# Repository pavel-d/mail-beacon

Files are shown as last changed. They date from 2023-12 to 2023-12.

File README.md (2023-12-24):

# Mail Beacon

The Mailbox Beacon is a device that detects when a new letter or package has been delivered to your mailbox using a reed switch. It sends a signal to your LoRa gateway, then the gateway sends a message via WiFi to MQTT server. It's designed to integrate with HomeAssistant, but can theoretically work with anything that supports MQTT based sensors.

Specification
--
- Microcontroller: Attiny1616
- Radio module: SX1278 LoRa 433 Mhz (Ai-Thinker-Ra-01)
- Sensor: Reed switch
- Voltage regulator: SPX3819M5-L-3-3
- Programming Protocol: UPDI
- Power consumption: in microamps range when asleep
- Gateway: LILYGO TTGO LoRa32 V2.1
- Status LED

Wiring
--
Reed switch (or any other kind of contact switch) must be connected either to PA4 or PA7 pins and to the GND. Pins have internal pull-ups enabled and are "active low", so the switch must pull the pin to the ground when circuit is closed. Both pins have interrupts attached, microcontroller will send a message to the gateway when the logic level changes.

TEST button also has an interrupt attached and can be used to test the setup.

Power LED has a jumper that can be cut to reduce the power consumption.

Battery monitoring
--
The beacon sends the battery voltage (in milivolts) in every LoRa packet, so that you know when you need to re-charge the battery.

Schematic
--
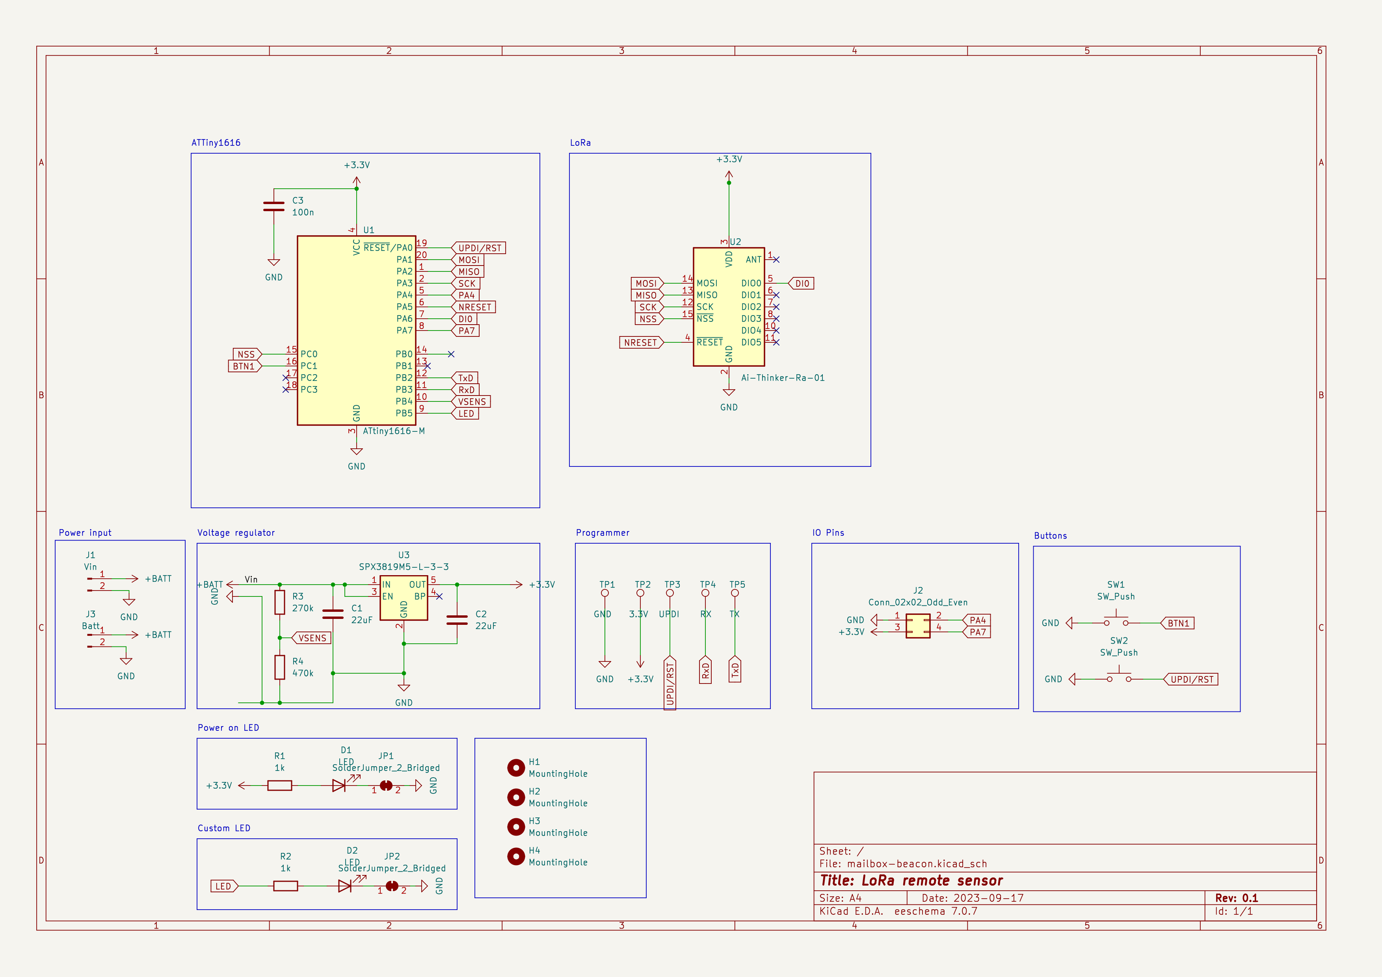
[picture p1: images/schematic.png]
schematic


Board
--
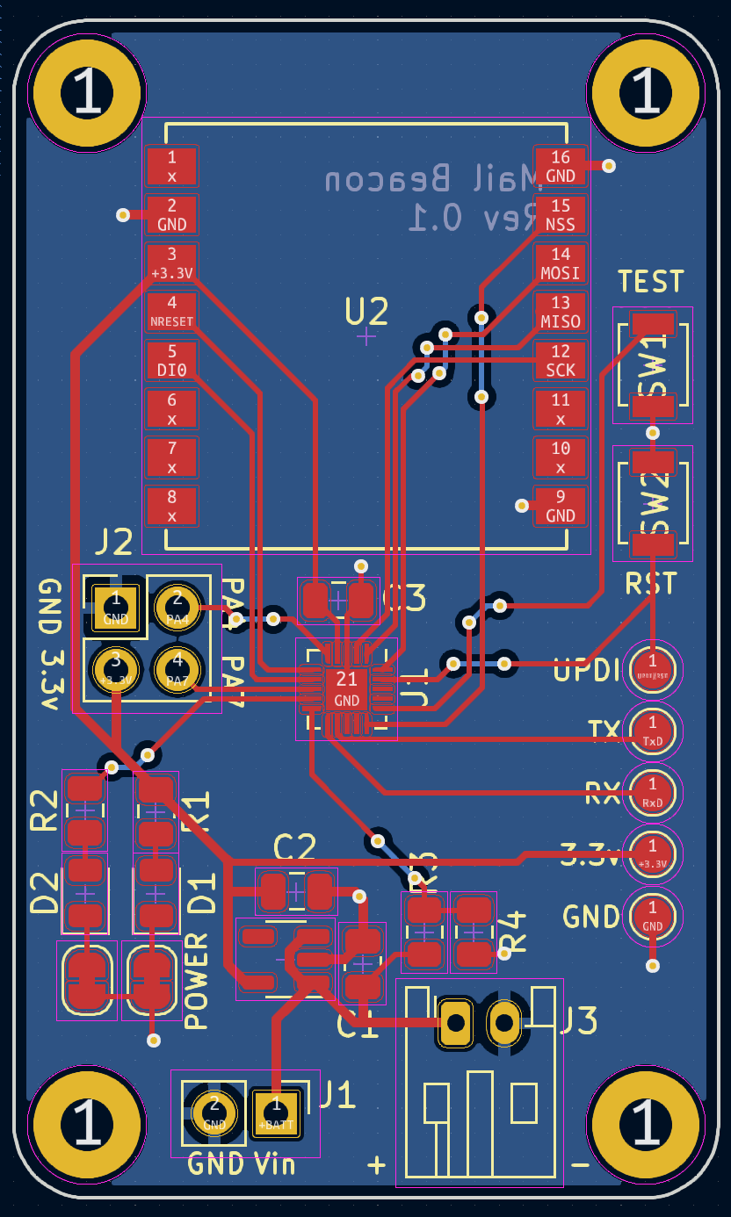
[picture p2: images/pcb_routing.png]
pcb


Images
--
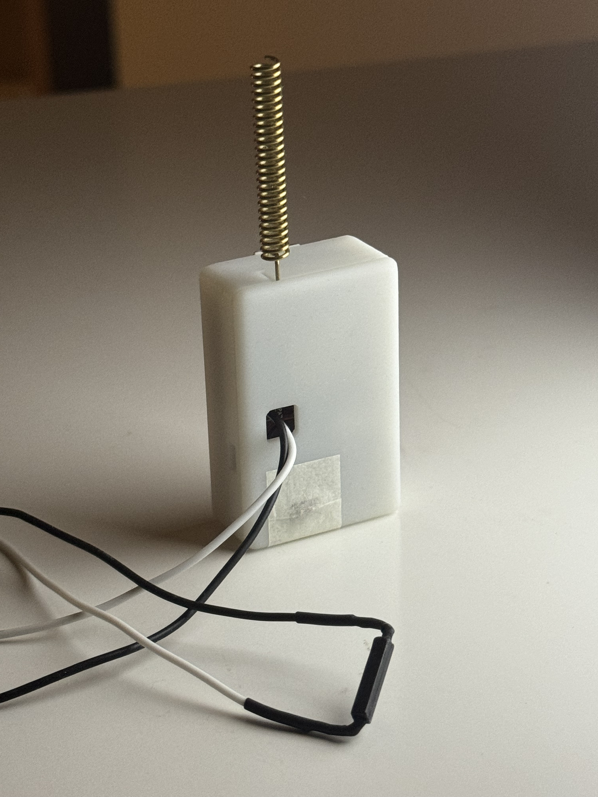
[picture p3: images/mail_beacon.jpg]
manufactured


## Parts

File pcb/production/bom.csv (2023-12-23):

Designator | Footprint | Quantity | Value | LCSC Part #
C1, C2 | 0805 | 2 | 22uF
C3 | 0805 | 1 | 100n
D1, D2 | 0805 | 2 | LED
H1, H2, H3, H4 | MountingHole_2.2mm_M2_Pad | 4 | MountingHole
J1 | PinHeader_1x02_P2.54mm_Vertical | 1 | Vin
J2 | PinHeader_2x02_P2.54mm_Vertical | 1 | Conn_02x02_Odd_Even
J3 | JST_PH_S2B-PH-K_1x02_P2.00mm_Horizontal | 1 | Batt
JP1, JP2 | SolderJumper-2_P1.3mm_Bridged_RoundedPad1.0x1.5mm | 2 | SolderJumper_2_Bridged
R1, R2 | 0805 | 2 | 1k
R3 | 0805 | 1 | 10k
R4 | 0805 | 1 | 20k
SW1, SW2 | SW_SPST_B3U-1000P | 2 | SW_Push
TP1 | TestPoint_Pad_D1.5mm | 1 | GND
TP2 | TestPoint_Pad_D1.5mm | 1 | 3.3V
TP3 | TestPoint_Pad_D1.5mm | 1 | UPDI
TP4 | TestPoint_Pad_D1.5mm | 1 | RX
TP5 | TestPoint_Pad_D1.5mm | 1 | TX
U1 | VQFN-20-1EP_3x3mm_P0.4mm_EP1.7x1.7mm | 1 | ATtiny1616-M
U2 | Ai-Thinker-Ra-01-LoRa | 1 | Ai-Thinker-Ra-01
U3 | SOT-23-5 | 1 | SPX3819M5-L-3-3

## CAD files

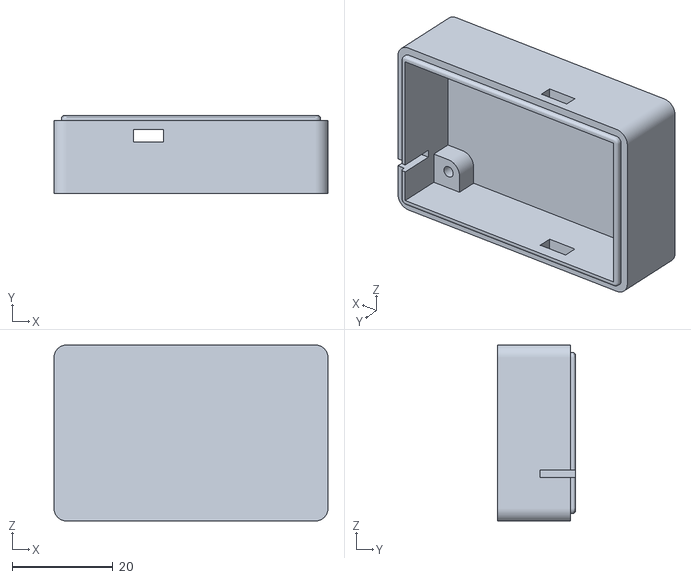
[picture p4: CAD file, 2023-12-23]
pcb/3dmodels/Case Bottom.stl
54.5 x 15.5 x 35.0

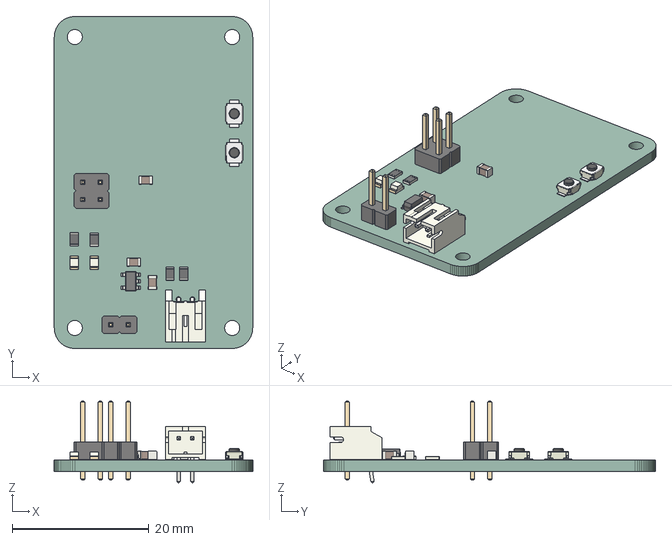
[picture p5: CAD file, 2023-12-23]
pcb/lora trigger attiny1616.step
29.0 x 48.5 x 11.9 mm
_autosave-lora trigger attiny1616 PCB

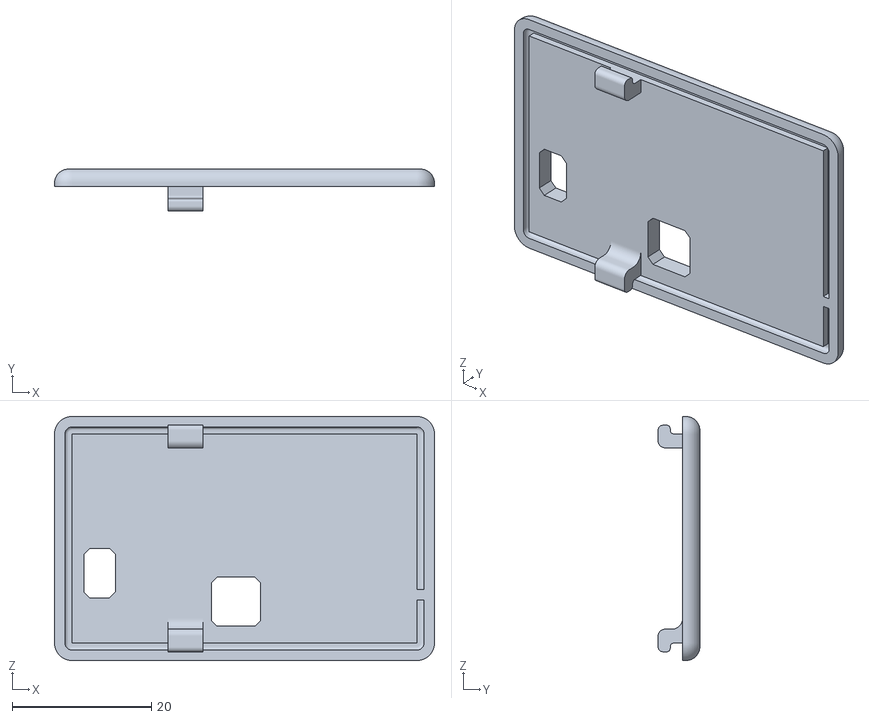
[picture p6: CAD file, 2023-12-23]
pcb/3dmodels/Case Top.stl
54.5 x 6.00 x 35.0

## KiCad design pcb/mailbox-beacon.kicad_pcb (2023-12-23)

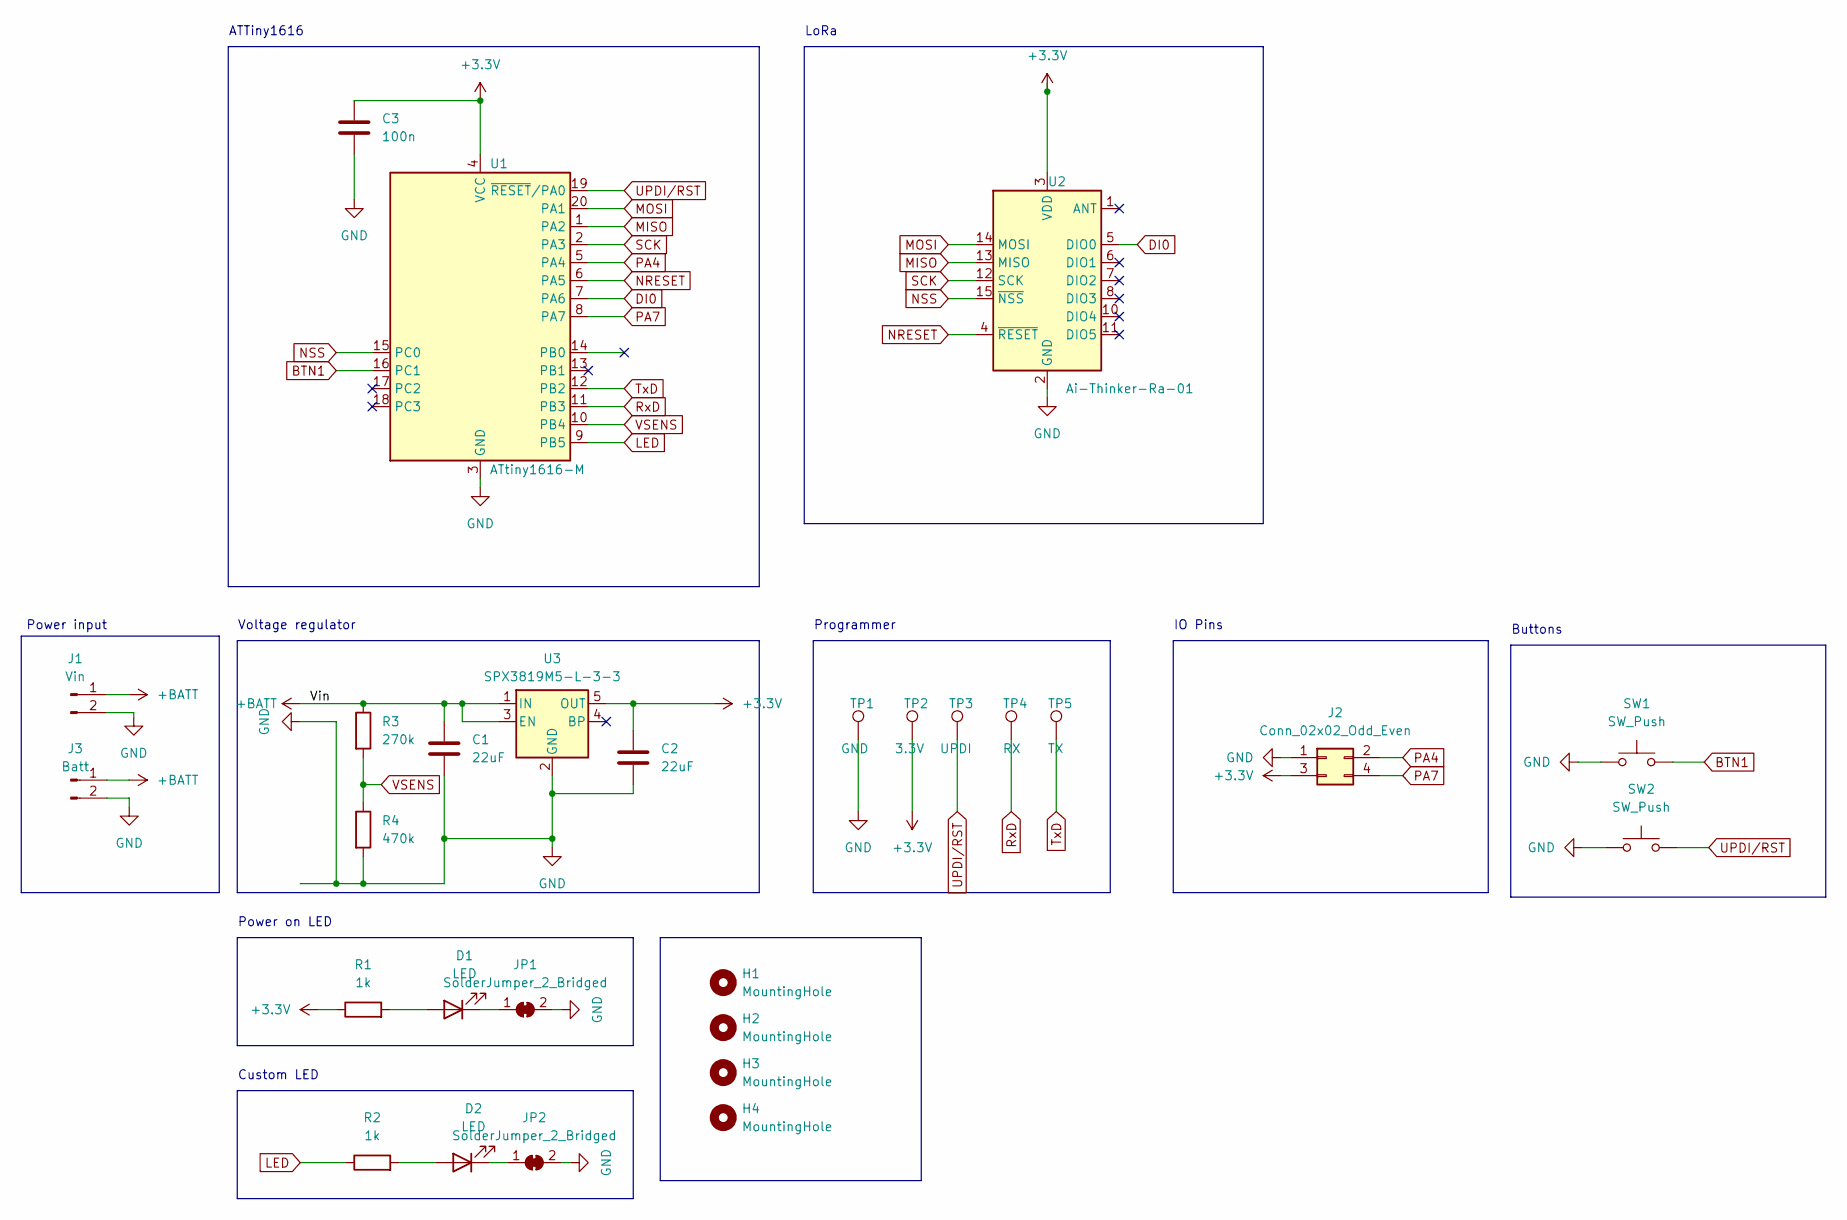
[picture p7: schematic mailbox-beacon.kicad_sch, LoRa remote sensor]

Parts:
C1, C2: 22uF; C_0805_2012Metric
C3: 100n; C_0805_2012Metric
D1, D2: LED; LED_0805_2012Metric
H1, H2, H3, H4: MountingHole; MountingHole_2.2mm_M2_Pad
J1: Vin; PinHeader_1x02_P2.54mm_Vertical
J2: Conn_02x02_Odd_Even; PinHeader_2x02_P2.54mm_Vertical
J3: Batt; JST_PH_S2B-PH-K_1x02_P2.00mm_Horizontal
JP1, JP2: SolderJumper_2_Bridged; SolderJumper-2_P1.3mm_Bridged_RoundedPad1.0x1.5mm
R1, R2: 1k; R_0805_2012Metric
R3: 270k; R_0805_2012Metric
R4: 470k; R_0805_2012Metric
SW1, SW2: SW_Push; SW_SPST_B3U-1000P
TP1: GND; TestPoint_Pad_D1.5mm
TP2: 3.3V; TestPoint_Pad_D1.5mm
TP3: UPDI; TestPoint_Pad_D1.5mm
TP4: RX; TestPoint_Pad_D1.5mm
TP5: TX; TestPoint_Pad_D1.5mm
U1: ATtiny1616-M; VQFN-20-1EP_3x3mm_P0.4mm_EP1.7x1.7mm
U2: Ai-Thinker-Ra-01; Ai-Thinker-Ra-01-LoRa
U3: SPX3819M5-L-3-3; SOT-23-5

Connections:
+3.3V: C2.1, C3.1, J2.3, R1.1, TP2.1, U1.4 (VCC), U2.3 (VDD), U3.5 (OUT)
+BATT: C1.1, J1.1, J3.1, R3.1, U3.1 (IN), U3.3 (EN)
BTN1: SW1.2, U1.16 (PC1)
DI0: U1.7 (PA6), U2.5 (DIO0)
GND: C1.2, C2.2, C3.2, J1.2, J2.1, J3.2, JP1.2 (B), JP2.2 (B), R4.2, SW1.1, SW2.1, TP1.1, U1.3 (GND), U1.21 (GND), U2.2 (GND), U2.9 (GND), U2.16 (GND), U3.2 (GND)
LED: R2.1, U1.9 (PB5)
MISO: U1.1 (PA2), U2.13 (MISO)
MOSI: U1.20 (PA1), U2.14 (MOSI)
NRESET: U1.6 (PA5), U2.4 (~RESET)
NSS: U1.15 (PC0), U2.15 (~NSS)
unnamed: D1.2 (A), R1.2
unnamed: D1.1 (K), JP1.1 (A)
unnamed: D2.2 (A), R2.2
unnamed: D2.1 (K), JP2.1 (A)
PA4: J2.2, U1.5 (PA4)
PA7: J2.4, U1.8 (PA7)
RxD: TP4.1, U1.11 (PB3)
SCK: U1.2 (PA3), U2.12 (SCK)
TxD: TP5.1, U1.12 (PB2)
UPDI/RST: SW2.2, TP3.1, U1.19 (~RESET/PA0)
VSENS: R3.2, R4.1, U1.10 (PB4)

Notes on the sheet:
Voltage regulator
IO Pins
Programmer
Buttons
Power on LED
Custom LED
Power input
LoRa
ATTiny1616

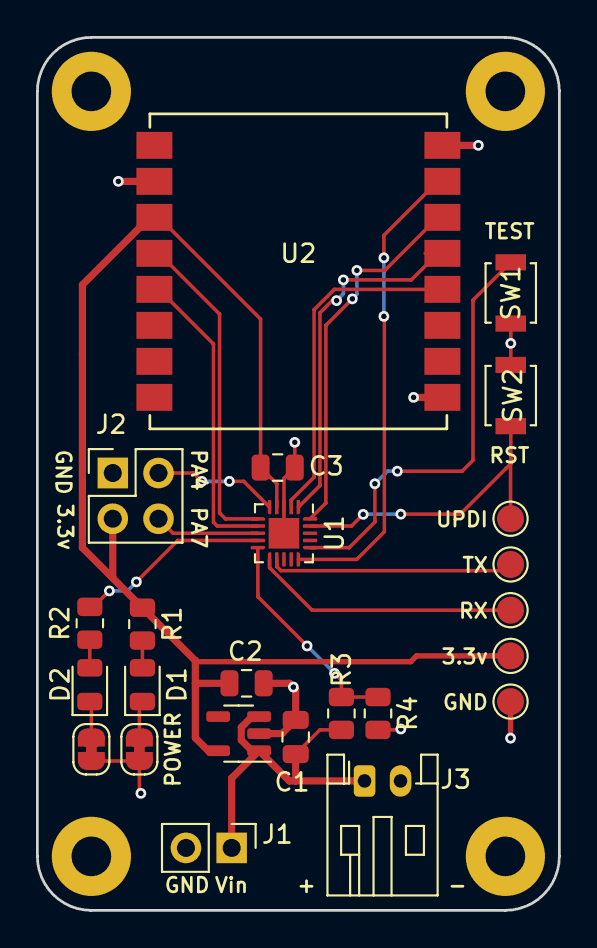
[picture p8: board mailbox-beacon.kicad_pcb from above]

Board: 2 copper layers, 29.0 x 48.5 mm, 28 parts (0 on the bottom side), 21 nets.

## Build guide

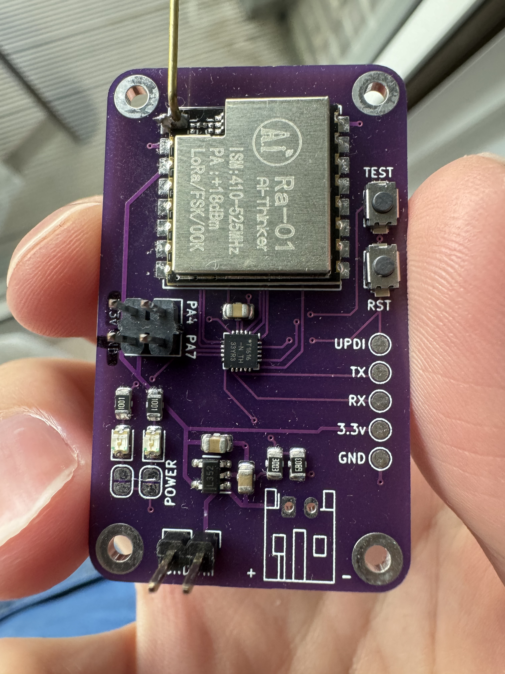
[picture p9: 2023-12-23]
images/pcb_manufactured.jpeg

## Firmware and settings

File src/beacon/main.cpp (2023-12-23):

#include <Arduino.h>
#include <SPI.h>
#include <LoRa.h>
#include <avr/sleep.h>
#include <OneButton.h>
#include <EEPROM.h>
#include "Beacon.h"
#include "Blink.h"
#include "Packet.h"

#define SyncWord 0xF3
#define TxPower 20
#define SignalBandwidth 125E3
#define SpreadingFactor 12
#define BAND 433E6  

#define NSS 10
#define MOSI 14
#define MISO 15
#define SCK 16

#define NRESET 1
#define DI01 2

#define BTN1 11
#define PA4 0
#define PA7 3
#define LED 4
#define VSENS 5

#define BEACON_ID_ADDRESS 0x00

long wokeUpAt;
bool shouldTransmit;
uint8_t beaconID[PACKET_BEACON_ID_SIZE];
enum BeaconMode { TRANSMIT = 0, RESET = 2};

// TRANSMIT is default
BeaconMode beaconMode = TRANSMIT;

// Calculated using linear regression
// Due to chosen resistor dividors values and min voltage reg value, the actual range
// is between 3300 and 4800 millivolts
float voltageMultiplier = 4813.6192;
float voltageIntercept = -10.7395;

void sleep() {
  Serial.flush();
  LoRa.sleep();
  set_sleep_mode(SLEEP_MODE_PWR_DOWN);
  sleep_enable();
  sleep_cpu();
}


void onClick() {
  shouldTransmit = true;
  sleep_disable();
}

void onLongPress() {
  beaconMode = RESET;
}

OneButton button(BTN1);
Beacon beacon;

void handleButtonInterrupt() {
  wokeUpAt = millis();
  button.tick();
}

void handleExternalTrigger() {
  shouldTransmit = true;
  sleep_disable();
}

void initBeaconID(bool force) {
  if (!force) {
    EEPROM.get(BEACON_ID_ADDRESS, beaconID);

    for (int i = 0; i < PACKET_BEACON_ID_SIZE; i++) {
      if (beaconID[i] != 0) {
        return; // Address has been previously initialized, no need to re-assign
      }
    }
  }

  // Generate a random ID and save to EEPROM
  randomSeed(analogRead(PIN_PB0));

  for (int i = 0; i < PACKET_BEACON_ID_SIZE; i++) {
    beaconID[i] = random(256);
  }

  EEPROM.put(BEACON_ID_ADDRESS, beaconID);
}

void setup() {
  initBeaconID(false);

  beacon.setBeaconID(beaconID);

  Serial.begin(9600);

  analogReference(VDD);
  pinMode(LED, OUTPUT);
  pinMode(PA4, INPUT_PULLUP);
  pinMode(PA7, INPUT_PULLUP);

  attachInterrupt(digitalPinToInterrupt(BTN1), handleButtonInterrupt, CHANGE);
  attachInterrupt(digitalPinToInterrupt(PA4), handleExternalTrigger, CHANGE);
  attachInterrupt(digitalPinToInterrupt(PA7), handleExternalTrigger, CHANGE);

  button.attachClick(onClick);
  button.attachLongPressStart(onLongPress);
  button.attachDoubleClick(onLongPress);

  blink(LED);
  delay(500);

  LoRa.setPins(NSS, NRESET, DI01);
  LoRa.setSpreadingFactor(SpreadingFactor);
  LoRa.setSignalBandwidth(SignalBandwidth);
  LoRa.setSyncWord(SyncWord);
  LoRa.setTxPower(TxPower);
  
  delay(2000);

  if (!LoRa.begin(BAND)) {
    while (1) {
      blinkSlow(LED);
    }
  }

  Serial.println("Ready");

  blink(LED, 3);
}



void loop() {
  button.tick();

  switch (beaconMode)  {
  case TRANSMIT:
    if (shouldTransmit) {
      float val = float(analogReadEnh(VSENS, 12)) / float(4096);
      float miliVolts = val * voltageMultiplier + voltageIntercept;

      // When the device is connected via the programming header,
      // the voltage reading will be off
      if (miliVolts < 0) {
        miliVolts = 0;
      }

      if (beacon.transmit(digitalRead(PA4), digitalRead(PA7), digitalRead(BTN1), (uint16_t)miliVolts)) {
        blink(LED, 2);
      }

      shouldTransmit = false;
    }

    // Stay awake to correctly handle long button press
    if (millis() - wokeUpAt > 2000) {
      sleep();
    }

    break;

  case RESET:
    initBeaconID(true);
    beaconMode = TRANSMIT;
    blinkSlow(5);

  default:
    // This should never happen
    break;
  }
}

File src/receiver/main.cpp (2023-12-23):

#include <Arduino.h>
#include <SPI.h>
#include <LoRa.h>
#include <Adafruit_GFX.h>
#include <Adafruit_SSD1306.h>
#include <WiFi.h>
#include <PubSubClient.h>

#include "Packet.h"

#define SyncWord 0xF3
#define TxPower 20
#define SignalBandwidth 250E3
#define SpreadingFactor 12
#define BAND 433E6

#define SCK 5
#define MISO 19
#define MOSI 27
#define SS 18
#define RST 14
#define DIO0 26

//OLED pins
#define OLED_SDA    21
#define OLED_SCL    22
#define OLED_RST    -1
#define SCREEN_WIDTH 128 // OLED display width, in pixels
#define SCREEN_HEIGHT 64 // OLED display height, in pixels

const char* ssid = "My Wifi";
const char* password = "12345678";

const char *mqtt_server = "192.168.1.1";
const int mqtt_port = 31883;


Adafruit_SSD1306 display(SCREEN_WIDTH, SCREEN_HEIGHT, &Wire, OLED_RST);
WiFiClient wifiClient;
PubSubClient mqtt(wifiClient);

void blink(int c) {
  for (int i = 0; i <= c; i++) {
    digitalWrite(LED_BUILTIN, HIGH);
    delay(25);
    digitalWrite(LED_BUILTIN, LOW);
    delay(25);
  }
}

void blink() {
  blink(1);
}


void blinkSlow() {
  digitalWrite(LED_BUILTIN, HIGH);
  delay(1500);
  digitalWrite(LED_BUILTIN, LOW);
  delay(1500);
}

void reconnect() {
  while (!mqtt.connected()) {
    Serial.println("Re-connecting to MQTT");

    // Create a random client ID
    String clientId = "LoRaGateway-";
    clientId += String(random(0xffff), HEX);

    if (mqtt.connect(clientId.c_str())) {
    } else {
      Serial.print("MQTT failed, rc=");
      Serial.print(mqtt.state());
      Serial.println(" try again in 1 seconds");
      delay(1000);
    }
  }
}

void printReady() {
  display.clearDisplay();
  display.setCursor(0,0);
  display.println("WhisperLink Receiver");
  display.println("Waiting for data");

  display.display();
}

void printBeaconPacket(BeaconPacket packet, size_t packetSize) {
  display.clearDisplay();
  display.setCursor(0,0);
  display.println("Received packet");

  display.setCursor(0,20);
  display.print("Beacon ID: ");
  display.print(packet.beaconID, HEX);

  display.setCursor(0,30);
  display.printf("Size: %d bytes", packetSize);

  display.setCursor(0,50);
  display.printf("RSSI: %d, SNR: ", LoRa.packetRssi());
  display.print(LoRa.packetSnr());

  display.display();
}

void printBeaconParsingError(size_t packetSize) {
  display.clearDisplay();
  display.setCursor(0,0);
  display.println("Failed to parse beacon packet");

  display.setCursor(0,30);
  display.printf("Size: %d bytes", packetSize);

  display.setCursor(0,50);
  display.printf("RSSI: %d, SNR: %d", LoRa.packetRssi(), LoRa.packetSnr());

  display.display();
}


void setup() {
  pinMode(LED_BUILTIN, OUTPUT);

  //reset OLED display via software
  pinMode(OLED_RST, OUTPUT);
  digitalWrite(OLED_RST, LOW);
  delay(20);
  digitalWrite(OLED_RST, HIGH);

  Wire.begin(OLED_SDA, OLED_SCL);
  if(!display.begin(SSD1306_SWITCHCAPVCC, 0x3c, false, false)) { // Address 0x3C for 128x32
    for(;;); // Don't proceed, loop forever
  }

  display.clearDisplay();
  display.setTextSize(1);
  display.setTextWrap(1);
  display.setTextColor(WHITE);

  LoRa.setPins(SS, RST, DIO0);
  LoRa.setSyncWord(SyncWord);
  LoRa.setSpreadingFactor(SpreadingFactor);
  LoRa.setSignalBandwidth(SignalBandwidth);
  LoRa.setTxPower(TxPower);

  mqtt.setServer(mqtt_server, mqtt_port);
  // reconnect();
  
  delay(1000);

  if (!LoRa.begin(BAND)) {
    while (1) {
      blinkSlow();
    }
  }

  WiFi.mode(WIFI_STA);
  WiFi.begin(ssid, password);

  while (WiFi.status() != WL_CONNECTED){
    display.clearDisplay();
    display.setCursor(0,0);
    display.println("WhisperLink Receiver");
    display.printf("Connecting to Wi-Fi", ssid);
    display.display();

    delay(100);
  }

  Serial.begin(9600);
  Serial.println("Ready");
  printReady();
  blink(2);
}

void printByteArrayAsHex(uint8_t arr[], int length) {
  for (int i = 0; i < length; i++) {
    if (arr[i] < 0x10) {
      Serial.print("0");
    }
    Serial.print(arr[i], HEX);
    Serial.print(" ");
  }

  Serial.println();
}

void loop() {
  int packetSize = LoRa.parsePacket();

  if (!packetSize) {
    return;
  }

  byte buffer[packetSize + sizeof(int16_t) + sizeof(float)]; // + SNR and RSSI metadata

  for (int i = 0; i < packetSize; i++) {
    buffer[i] = LoRa.read();
  }

  Serial.print("Payload: ");
  printByteArrayAsHex(buffer, sizeof(buffer));

  BeaconPacket parsedPacket;
  if (!parsePacket(buffer, packetSize, parsedPacket)) {
    Serial.printf("Failed to parse packet: (%d bytes)\n", packetSize);
    printBeaconParsingError(packetSize);

    return;
  }

  parsedPacket.rssi = LoRa.packetRssi();
  parsedPacket.snr = LoRa.packetSnr();

  memcpy(buffer + packetSize, &parsedPacket.rssi, sizeof(int16_t));
  memcpy(buffer + packetSize + sizeof(int16_t), &parsedPacket.snr, sizeof(float));

  printBeaconPacket(parsedPacket, packetSize);

  Serial.printf("Received packet (%d bytes)\n", packetSize);

  if (!mqtt.connected()) {
    Serial.println("MQTT not connected");
    reconnect();
  }

  if (!mqtt.connected()) {
    Serial.println("Still not connected");
  }

  if (!mqtt.publish("whisper_link/beacons/raw_events", buffer, sizeof(buffer))) {
    Serial.println("publish() returned false");
  } else {
    Serial.printf("Published (%d bytes)\n", sizeof(buffer));
  }

  if (!mqtt.endPublish()) {
    Serial.println("endPublish() returned false");
  }

  if (!mqtt.loop()) {
    Serial.println("loop() returned false");
  }

  deallocateBeaconData(parsedPacket);

  blink();
}
